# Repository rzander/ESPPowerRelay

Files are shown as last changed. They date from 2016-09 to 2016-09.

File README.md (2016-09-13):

# DIY - Smart Home Power Relay (ESP8266)
There exists many Relay-Modules based on ESP8266 or other wireless Modules, but I could not find a Module that fits in a european Wallbox and is independent of protocols or wireless standards. That’s why I've created my own Solution: <br>
Power,Relay and ESP Module<br> 

> **Caution: These modules do not have any certifications… In most countries it’s not legal to use it in Production. <br>And: 230V AC can kill !**

The main goals for this Project are:
 -	As **small** as possible
 -	As **cheap** as possible
 -	As **save** as possible
 -	As **flexible** as possible

Specially the flexibility is something important for me, as I have different scenarios to fulfill and I want to be able to change the wireless technology if it’s required. This is the reason why the result is not a single Module, there are currently 3 Modules: Power, Relay and Wireless (currently based on a ESP8266-12) <br>
 <br>
 <br>
With a **size** of 45mm * 35mm * 20mm (Length, Width, Height) for all three Modules,  it's small enough to mount it in wall (e.g. behind a power switch).

The price for the material is around **14$ (for all three modules)**. 

Eagle and Gerber Files are part of this Project. The Modules are Open-Hardware, feel free to reproduce... Feedback is Welcome.

## Power Module
Input: 100-240V AC<br>
Output: 5V and 3.3V DC (3W Total)<br>
Size: 45mm * 20mm * 20mm (length, width, height)<br>
 <br>

### Schema
 <br>
### Layout
 <br>
### Bill of Materials

|Item|Price (USD)|
|:---|---:|
|1 * Fuse 500ma (MF2410F0.500TM)|0.30|
|1 * Connector Block (4-Ports)|0.70|
|2 * 47uF Tantal Capacitor|0.90|
|1 * Voltage Regulator 3.3V (MC33269ST-3.3T3G)|0.90|
|1 * Power-Supply 5VDC 3W (Hi-Link)|2.75|
|1 * Print|1.00|
|Total:|6.55|

## ESP Module
Size: 40mm * 20mm * 5mm (length, width, height)<br>
<br>

### Schema
 <br>
### Layout
 <br>
### Bill of Materials

|Item|Price (USD)|
|:---|---:|
|4 * Resistor 10k|0.45|
|1 * ESP8266-12F|1.75|
|1 * Print|1.00|
|Total:|3.20|

## Relay Module
Input: PWR 5V, Signal 3V<br>
Output: 250V 10A<br>
Size: 45mm * 10mm * 20mm (length, width, height)<br>
 <br>

### Schema
 <br>

### Layout
 <br>

### Bill of Materials

|Item|Price (USD)|
|:---|---:|
|1 * Gate Driver (MDC3105LT1G)|0.50|
|1 * Relay (ALQ305)|2.35|
|1 * Connector Block (2 Ports)|0.30|
|1 * Print|1.00|
|Total:|4.15|

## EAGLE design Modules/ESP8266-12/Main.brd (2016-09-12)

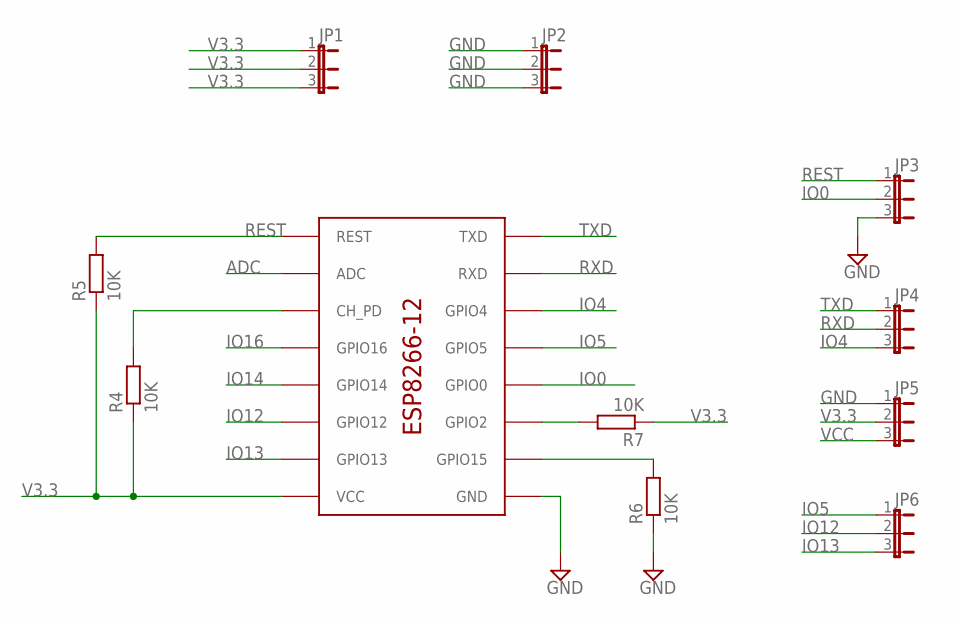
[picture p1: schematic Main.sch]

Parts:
JP1, JP2, JP3, JP4, JP5, JP6: JP2E; JP2
R4, R5, R6, R7: 10K; M0805
U$1: ESP8266-12

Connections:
ADC: U$1.ADC
GND: JP2.1, JP2.2, JP2.3, JP3.3, JP5.1, R6.1, U$1.GND
IO0: JP3.2, U$1.GPIO0
IO4: JP4.3, U$1.GPIO4
IO5: JP6.1, U$1.GPIO5
IO12: JP6.2, U$1.GPIO12
IO13: JP6.3, U$1.GPIO13
IO14: U$1.GPIO14
IO16: U$1.GPIO16
unnamed: R4.2, U$1.CH_PD
unnamed: R6.2, U$1.GPIO15
unnamed: R7.2, U$1.GPIO2
REST: JP3.1, R5.2, U$1.REST
RXD: JP4.2, U$1.RXD
TXD: JP4.1, U$1.TXD
V3.3: JP1.1, JP1.2, JP1.3, JP5.2, R4.1, R5.1, R7.1, U$1.VCC
VCC: JP5.3

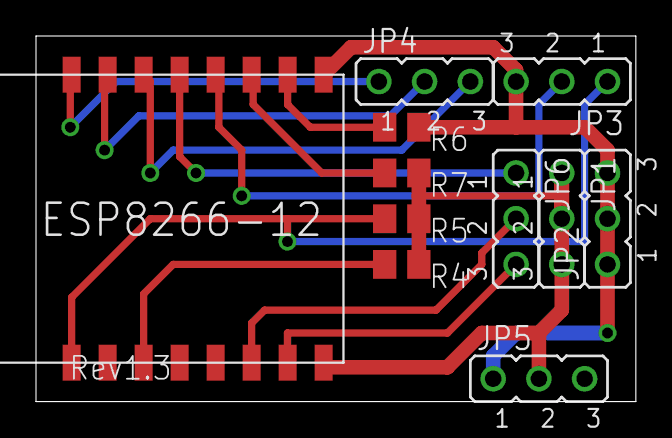
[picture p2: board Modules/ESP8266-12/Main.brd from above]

Board: 2 copper layers, 33.3 x 20.3 mm, 11 parts (0 on the bottom side), 13 nets.

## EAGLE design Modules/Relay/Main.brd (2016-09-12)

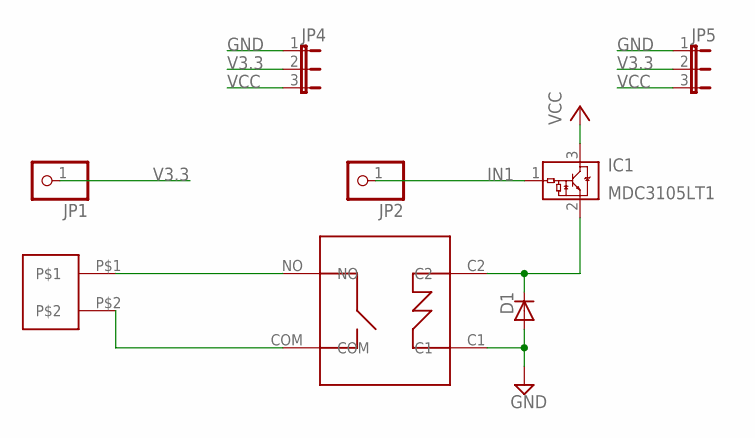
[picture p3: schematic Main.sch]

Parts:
D1: DIODE-SOD123; SOD123
IC1: MDC3105LT1; SOT23
JP1, JP2: PINHD-1X1; 1X01
JP4, JP5: JP2E; JP2
REL1: ALQ305
U$2: 1713017

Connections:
GND: D1.A, JP4.1, JP5.1, REL1.C1
IN1: IC1.1 (VIN), JP2.1
unnamed: D1.C, IC1.2 (GND), REL1.C2
P$1: REL1.NO, U$2.P$1
P$2: REL1.COM, U$2.P$2
V3.3: JP1.1, JP4.2, JP5.2
VCC: IC1.3 (VOUT), JP4.3, JP5.3

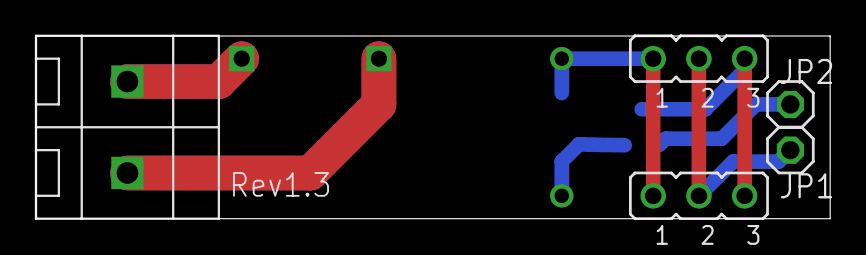
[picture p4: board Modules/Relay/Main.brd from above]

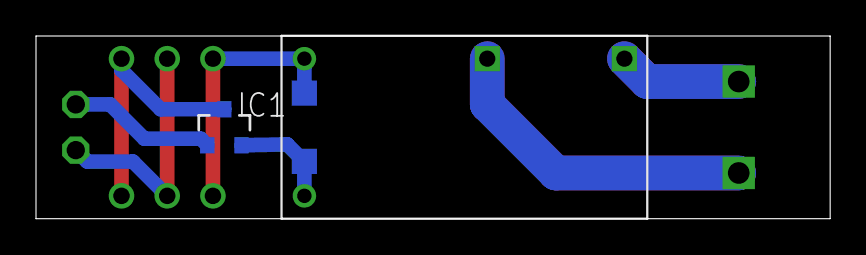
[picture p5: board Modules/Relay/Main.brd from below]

Board: 2 copper layers, 44.1 x 10.2 mm, 8 parts (3 on the bottom side), 7 nets.

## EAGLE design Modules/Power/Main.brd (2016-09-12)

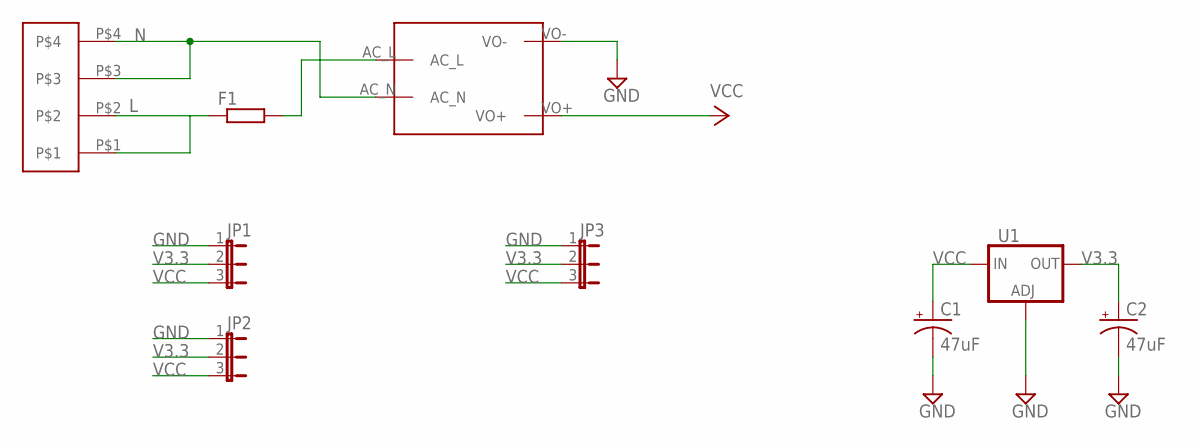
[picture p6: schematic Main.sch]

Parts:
17928891: 1792889
C1, C2: 47uF; EIA3528
F1: R-EU_R2010W; R2010W
JP1, JP2, JP3: JP2E; JP2
PWR1: MAINS_CONVERTERS; HLK-PM01
U1: V_REG_3.3V; SOT223

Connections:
GND: C1.C (-), C2.C (-), JP1.1, JP2.1, JP3.1, PWR1.VO-, U1.1 (ADJ)
L: 17928891.P$1, 17928891.P$2, F1.1
N: 17928891.P$3, 17928891.P$4, PWR1.AC_N
unnamed: F1.2, PWR1.AC_L
V3.3: C2.A (+), JP1.2, JP2.2, JP3.2, U1.2 (OUT)
VCC: C1.A (+), JP1.3, JP2.3, JP3.3, PWR1.VO+, U1.3 (IN)

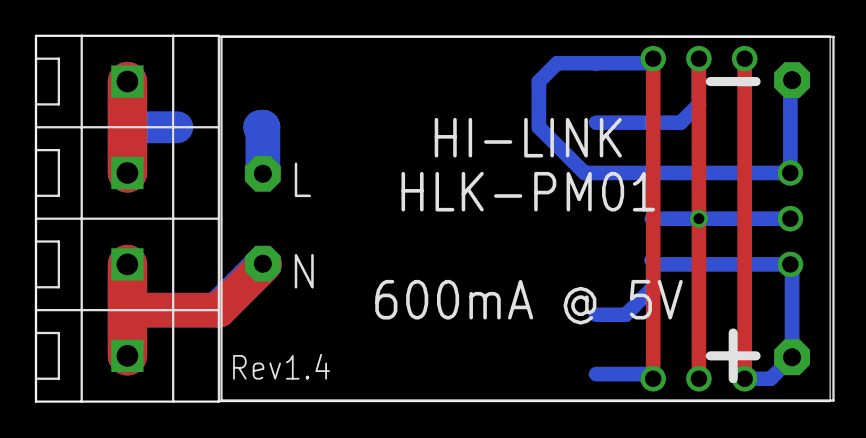
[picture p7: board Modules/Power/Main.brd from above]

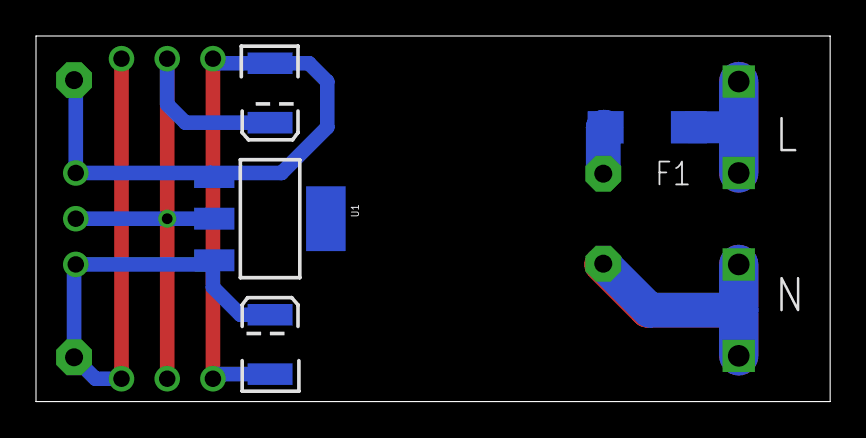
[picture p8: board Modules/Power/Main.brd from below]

Board: 2 copper layers, 44.1 x 20.3 mm, 9 parts (4 on the bottom side), 6 nets.

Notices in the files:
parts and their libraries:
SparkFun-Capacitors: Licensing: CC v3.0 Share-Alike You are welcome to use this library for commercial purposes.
